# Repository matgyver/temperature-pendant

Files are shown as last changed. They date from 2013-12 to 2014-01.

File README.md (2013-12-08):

/*
 * BlinkM Necklace with temperature sensor and switch
 * This will read in a temperature sensor and set the color
 * of the RGB LED accordingly.  A switch is used to rotate between
 * Temp mode, color mode and simulated off (LED is off, proc still running)
 * 
 * 2013 Matthew E. Nelson - Aerodyne Labs
 * www.rfgeeks.com          www.aerodynelabs.com
 */

/* Notes on this project - Please Read This if you are having problems!

Known Issues

*  There is some delay with the switch and switching modes, this is due to the software PWM, see note below

---------------------------------------------------------------------------------------------------------------

This project uses a BlinkM or MiniM module to read a temp sensor (analog) and use that to control the RGB LED on the module
The BlinkM/MiniM modules have an ATTiny85 (MiniM) or ATTiny44 (BlinkM).  While these processors do have PWM, the pins on the RGB
are not tied to the hardware PWM outputs except for Blue.  Therefore, a software based PWM was needed.  The software PWM that I am
using (see note below on original Author) does a pretty good job, but does have some limitiations.  This is mainly due to the fact 
that the ATTiny processors only have 1 timer.  The values that I choose was picked to produce as smooth of a result I could get while 
keeping the functionaility consistent.

Programming this requires a programmer as the BlinkM or MiniM do not have an arduino comptabible bootloader (or a HW serial port for that matter).  
For this reason you will need an ISP.  Fortunatly you can use an Arduino as an ISP.  Instructions for programming the BlinkM and MiniM can be 
found on ThingM's blog:  http://blog.thingm.com/2011/03/blinkm-smart-led-as-the-smallest-arduino/.  It's a little dated but still applies.

In addition, you will need to add the ATTiny44 and 85 processors to the Arduino IDE.  You can information about this on MIT's website located
here:  http://hlt.media.mit.edu/?p=1695.  There is a known issue with the Arduino IDE being able to address the full 8KB on the processor.  To fix
this issue, see this:  https://github.com/TCWORLD/ATTinyCore/tree/master/PCREL%20Patch%20for%20GCC.  Basically there is a problem with the version
of the compilier that Arduino uses, so this patch will fix that bug that limits it from compiling for programs larger than 4KB.  

UPDATE!
Through this process I ended up switching cores.  This was mainly due to the addition of using an ISR.  You can find the core I used here https://code.google.com/p/arduino-tiny/

Another note on the ISR.  The ISR does indeed work, however since the softwarePWM also uses that timer, it has to finish that before it goes to the ISR.  The result is that if
you push the button and it is pulsing a color, it will not move to the next mode until the the fade is complete.  Remember, it's a "feature".

The Software PWM routine was original written by Ernst Christensen and was found in the following Arduino forum thread: 
http://arduino.cc/forum/index.php/topic,75334.0.html

All credit goes to him for the handy routine

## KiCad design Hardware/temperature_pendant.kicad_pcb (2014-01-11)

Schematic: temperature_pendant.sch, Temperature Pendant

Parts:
BT1: BATTERY
C1, C3: .1 uF
C2: 4.7uF
D1: LED
J1: CONN-6
J2: USB_MINI
R1: 330
R2: 2K
R3: 10k
SW1: SW-MOM
U1: MCP73831/2
U2: BLINKM/MINM
U3: TMP3X

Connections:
+BATT: BT1.1 (+), C1.1, C3.2, J1.3, SW1.2, U1.3 (V_BAT), U2.3 (Vdd), U3.1 (Vs)
GND: BT1.2 (-), C1.2, C2.2, C3.1, J1.2, J2.5, R2.2, R3.2, U1.2 (Vss), U2.2 (GND), U3.3 (GND)
MISO: J1.6, U2.6 (MISO)
unnamed: R2.1, U1.5 (PROG)
unnamed: D1.1 (A), R1.1
unnamed: D1.2 (K), U1.1 (STAT)
unnamed: C2.1, J2.1, R1.2, U1.4 (V_DD)
RST: J1.1, U2.1 (RST)
SW: J1.4, R3.1, SW1.1, U2.4 (SDA/PWM)
TEMP: J1.5, U2.5 (SCL/AIN), U3.2 (Vout)

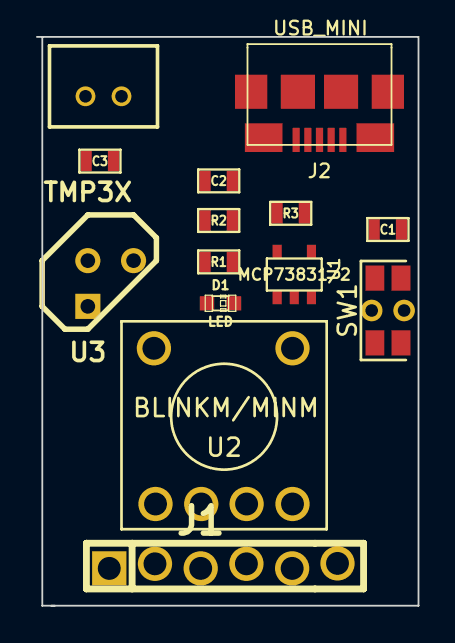
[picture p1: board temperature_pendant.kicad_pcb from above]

Board: 2 copper layers, 21.2 x 31.6 mm, 14 parts (0 on the bottom side), 10 nets, no tracks yet.

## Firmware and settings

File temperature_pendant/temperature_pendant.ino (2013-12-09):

/*
 * BlinkM Necklace with temperature sensor and switch
 * This will read in a temperature sensor and set the color
 * of the RGB LED accordingly.  A switch is used to rotate between
 * Temp mode, color mode and simulated off (LED is off, proc still running)
 * 
 * 2013 Matthew E. Nelson - Aerodyne Labs
 * www.rfgeeks.com          www.aerodynelabs.com
 */

/* Notes on this project - Please Read This if you are having problems!

Known Issues

*  There is some delay with the switch and switching modes, this is due to the software PWM, see note below

---------------------------------------------------------------------------------------------------------------

This project uses a BlinkM or MiniM module to read a temp sensor (analog) and use that to control the RGB LED on the module
The BlinkM/MiniM modules have an ATTiny85 (MiniM) or ATTiny44 (BlinkM).  While these processors do have PWM, the pins on the RGB
are not tied to the hardware PWM outputs except for Blue.  Therefore, a software based PWM was needed.  The software PWM that I am
using (see note below on original Author) does a pretty good job, but does have some limitiations.  This is mainly due to the fact 
that the ATTiny processors only have 1 timer.  The values that I choose was picked to produce as smooth of a result I could get while 
keeping the functionaility consistent.

Programming this requires a programmer as the BlinkM or MiniM do not have an arduino comptabible bootloader (or a HW serial port for that matter).  
For this reason you will need an ISP.  Fortunatly you can use an Arduino as an ISP.  Instructions for programming the BlinkM and MiniM can be 
found on ThingM's blog:  http://blog.thingm.com/2011/03/blinkm-smart-led-as-the-smallest-arduino/.  It's a little dated but still applies.

In addition, you will need to add the ATTiny44 and 85 processors to the Arduino IDE.  You can information about this on MIT's website located
here:  http://hlt.media.mit.edu/?p=1695.  There is a known issue with the Arduino IDE being able to address the full 8KB on the processor.  To fix
this issue, see this:  https://github.com/TCWORLD/ATTinyCore/tree/master/PCREL%20Patch%20for%20GCC.  Basically there is a problem with the version
of the compilier that Arduino uses, so this patch will fix that bug that limits it from compiling for programs larger than 4KB.  

UPDATE!
Through this process I ended up switching cores.  This was mainly due to the addition of using an ISR.  You can find the core I used here https://code.google.com/p/arduino-tiny/

Another note on the ISR.  The ISR does indeed work, however since the softwarePWM also uses that timer, it has to finish that before it goes to the ISR.  The result is that if
you push the button and it is pulsing a color, it will not move to the next mode until the the fade is complete.  Remember, it's a "feature".

The Software PWM routine was original written by Ernst Christensen and was found in the following Arduino forum thread: 
http://arduino.cc/forum/index.php/topic,75334.0.html

All credit goes to him for the handy routine
*/

#include "PinChangeInterrupt.h"
// BlinkM / MinM pins
const int redPin = 3;  // 
const int grnPin = 4;  //
const int bluPin = 1;  // PWM, will blink when programming
const int sdaPin = 0;  // PWM, 'd' pin, can be digital I/O
const int sclPin = 2;  // A/D, 'c' pin, can be digital I/O, or analog input

volatile long lastDebounceTime = 0;   // the last time the interrupt was triggered

//Defines
#define fadeSpeed 15             //Defines how fast we fade in the SoftPWM routine

//the debounce time in ms; decrease if quick button presses are ignored, increase
//if you get noise (multipule button clicks detected by the code when you only pressed it once)
#define debounceDelay 50         

//Defines the 2.56V internal voltage reference for use in the analogReference function
#define INTERNAL2V56_NO_CAP (6)

//Variable setup and initialize
int SW_Pin = sdaPin;             //Digital in pin for reading switch
const int tmp36_Pin  = A1;       //Analog in pin for TMP36 temp sensor and A1 because Arduino is stupid
const int numReadings = 10;      //Number of readings to take to average out the values

//Setup variables and set default values
int temperature = 0;
int mode = 1;

//Array used for averaging temperature values
int readings[numReadings];
int index = 0;
int total = 0;
int average = 0;
//Set RGB values to zero
int r,g,b = 0;

//  Setup routine, configures our pins and initializes a few things
void setup() 
{
  
  // initialize all the readings and array to 0 
  for (int thisReading = 0; thisReading < numReadings; thisReading++)
    readings[thisReading] = 0;   
  //configures the pins to the BlinkM module
  pinMode(redPin, OUTPUT);
  pinMode(grnPin, OUTPUT);
  pinMode(bluPin, OUTPUT); 

// Configures the Switch and TMP36 sensor pins
  pinMode(SW_Pin, INPUT);
  digitalWrite(SW_Pin, LOW);
  pinMode(tmp36_Pin, INPUT);
  
//Turn on the internal voltage reference for ADC since our source voltage varies, uses the ATTiny 2.56V internal ref.
  analogReference(INTERNAL2V56_NO_CAP);  
  
//Setup interrupt for switching modes
  attachPcInterrupt(0,SWITCH_ISR,RISING);
  
//  This is a short "Hello" to show we have initialized and setup everything
// This will blink each color once to make sure the RGB LED is functioning

  digitalWrite(grnPin, HIGH);     
  delay(250);
  digitalWrite(grnPin, LOW);
  delay(250);
  digitalWrite(bluPin, HIGH);     
  delay(250);
  digitalWrite(bluPin, LOW);
  delay(250);
  digitalWrite(redPin, HIGH);     
  delay(250);
  digitalWrite(redPin, LOW);
  delay(250);
  digitalWrite(redPin, HIGH);
  digitalWrite(bluPin, HIGH);
  digitalWrite(grnPin, HIGH);
  delay(250);
  digitalWrite(redPin, LOW);
  digitalWrite(bluPin, LOW);
  digitalWrite(grnPin, LOW);
  delay(250);
}

//  Main Loop

void loop() 
{
  if (mode > 6) 
    mode = 1;
    
    switch (mode) {
      case 1:  //Set LED color based on temp, default mode
        set_color_by_temp();
        break;
      case 2: //Rotate flashing each pin on the RGB
        flash_rgb();
        break;
      case 3: //Pulse a purple color
        pulse_purple();
        break;
      case 4: //Pulse a red color
        pulse_red();
        break;
      case 5: //Pulse a white color
        pulse_white();
        break;
      case 6: //"Off" mode, not a true off, but we are not burning current in the LEDs
        digitalWrite(redPin, LOW);
        digitalWrite(bluPin, LOW);
        digitalWrite(grnPin, LOW);
        delay(250);
        break;
      default:
        mode = 1;     
  
  }

}

/* Switch ISR Routine
This routine handles the switch and debounce.  If the switch is pressed, we want to increment the mode
We also want to handle a debounce on the switch, so we use the millis function to count so much before
actually acting on the switch, if the switch is still pressed, we increment
Because of the millis function, this ISR can not happen right away when the LEDs are using the Software PWM
So there will be a delay during these times until the fade is complete.  Consider this a "feature"
*/
void SWITCH_ISR(){
  
  if ((millis() - lastDebounceTime) > debounceDelay) //if current time minus the last trigger time is greater than
    {                                                  //the delay (debounce) time, button is completley closed.
      lastDebounceTime = millis();
   
      mode++;
    }

}

//This function reads the temp sensor and then sets the color of the RGB based on that value
void set_color_by_temp (void) {

  int sensorValue = analogRead(tmp36_Pin);
  int temperature = sensorValue * 2.56; 
  
/* Average routine
   In order to help smooth out the readings, we will take several measurements
   and average them out.  This does mean that upon initial startup, it will start
   at zero and pulse blue.  Once enough readings have been taken it will go to the 
   right color
   */
   
  // subtract the last reading:
  total = total - readings[index]; 
  
  // read from the sensor:  
  readings[index] = temperature; 
  
  // add the reading to the total:
  total = total + readings[index];       
  
  // advance to the next position in the array:  
  index = index + 1;                    

  // if we're at the end of the array...
  if (index >= numReadings)              
    // ...wrap around to the beginning: 
    index = 0;                           

  // calculate the average:
  temperature = total / numReadings;
  
  //Here we determine the color base on the readings in millivolts.  This was done as doing
  //a full conversion to a temperature was causing some issues.  We are not sending out the temp data
  //so there is no need for this, but using the millivolts value does keep it fairly easy to read
  
  //If less than 0 C, pulse blue
  if (temperature < 500)
  {
    for(int fadeValue = 1; fadeValue < 254; fadeValue++) { 
    softPWM(bluPin, fadeValue, fadeSpeed);
    digitalWrite(grnPin, LOW);
    digitalWrite(redPin, LOW);
    }
    
    for(int fadeValue = 253; fadeValue > 1; fadeValue--) { 
    softPWM(bluPin, fadeValue, fadeSpeed);
    digitalWrite(grnPin, LOW);
    digitalWrite(redPin, LOW);
    }
  }
  //If between 0 and 25 C, fade from blue to green
  else if(temperature < 750 && temperature >= 500)
  {
    g = map(temperature, 500, 750, 1, 254);
    b = map(temperature, 500, 750, 254, 1);
    softPWM(grnPin, g, fadeSpeed);
    softPWM(bluPin, b, fadeSpeed);
    digitalWrite(redPin, LOW);
    
  }
  //If between 25 and 50 C, fade from green to red
  else if(temperature < 950 && temperature >= 750)
  {
    r = map(temperature, 750, 950, 1, 254);
    g = map(temperature, 750, 950, 254, 1);
    softPWM(grnPin, g, fadeSpeed);
    softPWM(redPin, r, fadeSpeed);
    digitalWrite(bluPin, LOW);
    
  }
  
  //If the temperature is hot, over 50 C, pulse red quickly
  else if (temperature >= 950)
  {
    for(int fadeValue = 1; fadeValue < 254; fadeValue++) { 
    softPWM(redPin, fadeValue, 5);
    digitalWrite(grnPin, LOW);
    digitalWrite(bluPin, LOW);
    }
    
    for(int fadeValue = 253; fadeValue > 1; fadeValue--) { 
    softPWM(redPin, fadeValue, 5);
    digitalWrite(grnPin, LOW);
    digitalWrite(bluPin, LOW);
    }
  }
}

//This routine flashes each RGB LED in sequence and the speed depends on the temperature value
void flash_rgb(void) {
  
  //Read the sensor, convert to milliVolt
  int sensorValue = analogRead(tmp36_Pin);
  int temperature = sensorValue * 2.56; 
  
  //Map the millis to a range of delay values
  int sp = map(temperature, 500, 950, 350, 100);
  
  digitalWrite(grnPin, HIGH);     
  delay(sp);
  digitalWrite(grnPin, LOW);
  delay(sp);
  digitalWrite(bluPin, HIGH);     
  delay(sp);
  digitalWrite(bluPin, LOW);
  delay(sp);
  digitalWrite(redPin, HIGH);     
  delay(sp);
  digitalWrite(redPin, LOW);
  delay(sp);
  digitalWrite(redPin, LOW);
  digitalWrite(bluPin, LOW);
  digitalWrite(grnPin, LOW);
  delay(sp);
}

void pulse_purple(void) {
  int fadeValue = 0;
  
  // fade in from min to max in increments of 5 points:
  for(int fadeValue = 1; fadeValue < 254; fadeValue++) { 
    // sets the value (range from 0 to 255):
    digitalWrite(grnPin, LOW);
    softPWM(redPin, fadeValue, fadeSpeed);
    softPWM(bluPin, fadeValue, fadeSpeed);
                         
  } 

  // fade out from max to min in increments of 5 points:
  for(int fadeValue = 254; fadeValue > 1; fadeValue--) { 
    // sets the value (range from 0 to 255):
    digitalWrite(grnPin, LOW);
    softPWM(redPin, fadeValue, fadeSpeed);
    softPWM(bluPin, fadeValue, fadeSpeed);                        
  }
}

void pulse_white(void) {
  int fadeValue = 0;
  
  // fade in from min to max in increments of 5 points:
  for(int fadeValue = 1; fadeValue < 254; fadeValue++) { 
    // sets the value (range from 0 to 255):
    softPWM(grnPin, fadeValue, fadeSpeed);
    softPWM(redPin, fadeValue, fadeSpeed);
    softPWM(bluPin, fadeValue, fadeSpeed);
                         
  } 

  // fade out from max to min in increments of 5 points:
  for(int fadeValue = 254; fadeValue > 1; fadeValue--) { 
    // sets the value (range from 0 to 255):
    softPWM(grnPin, fadeValue, fadeSpeed);
    softPWM(redPin, fadeValue, fadeSpeed);
    softPWM(bluPin, fadeValue, fadeSpeed);                        
  }
}

void pulse_red(void) {
  int fadeValue = 0;
  
  // fade in from min to max in increments of 5 points:
  for(int fadeValue = 1; fadeValue < 254; fadeValue++) { 
    // sets the value (range from 0 to 255):
    digitalWrite(grnPin, LOW);
    softPWM(redPin, fadeValue, fadeSpeed);
    digitalWrite(bluPin, LOW);
                         
  } 

  // fade out from max to min in increments of 5 points:
  for(int fadeValue = 254; fadeValue > 1; fadeValue--) { 
    // sets the value (range from 0 to 255):
    digitalWrite(grnPin, LOW);
    softPWM(redPin, fadeValue, fadeSpeed);
    digitalWrite(bluPin, LOW);                        
  }
}

//software PWM function that fakes analog output
// Function reads in the pin,  duty cycle (brightness), and fade speed)
// Duty cycle is 1-254
void softPWM(int pin, int freq, int sp) {
  digitalWrite(pin,HIGH); //on
  delayMicroseconds(sp*freq);
  digitalWrite(pin,LOW); //off
  delayMicroseconds(sp*(255-freq));
}

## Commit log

2013-10-21 Initial commit on hardware
    Start on schematic
    [temperature_pendant.sch]
2013-10-22 Added additional components
    Added BlinkM andprogramming header to schematic.
    [temperature_pendant.sch]
2013-10-26 Updates
    Completed schematic. Minor revisions, added comments to Arduino code.
    Fixed Library reference issue.
    [temperature_pendant.sch]
2013-10-26 PCB added
    First cut of the PCB layout
    [temperature_pendant.kicad_pcb]
2013-10-27 Updated board
    Updated board and first revision routing
    [temperature_pendant.dsn, temperature_pendant.kicad_pcb, temperature_pendant.sch]
2013-10-28 Added Gerber files
    Added Gerber and 3D file
    [temperature_pendant-B_Cu.gbl, temperature_pendant-B_Mask.gbs, temperature_pendant-B_SilkS.gbo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]
2013-11-05 Fixed Gerber issue
    Fixed Gerber issue
    [temperature_pendant.kicad_pcb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]
2013-11-06 Added drill hole
    Added a mechanical hole that could be used for chain for the pendant.
    [temperature_pendant.kicad_pcb]
2013-11-17 Updates
    Minor updates based on testing with the actual board.
2013-11-17 Fixed sensor, added locking connector
    Fixed the backward wiring on the sensor, added locking connector. Fixes
    issue #4 for the sensor and issue #3 for the locking connector.
    [temperature_pendant.kicad_pcb]
2013-11-17 Minor change cleanup
    Moved switch and battery connector. Cleaned up tracks in preparation
    for a redo on the layout.
    [temperature_pendant.kicad_pcb]
2013-11-17 Final cleanup and new routed board
    Re-routed board based on new placement
    [temperature_pendant.dsn, temperature_pendant.kicad_pcb]
2013-12-02 Added ISR routine
    Added a ISR to better handle the button presses to switch modes.
    Cleaned up other aspects of the code. Still have some debugging to
    do...
2013-12-03 Added debounce
    Added debounce routine to ISR to better handle switch. HW change will
    also help address some issues in the next HW Rev. Cleaned up some code,
    tweaked temperature mapping values. Added some other "flashy" modes.
    [temperature_pendant.ino]
2013-12-07 Enabled built-in pull ups
    Enabled built-in pull down resistor to better stabilize the SW input.
    Testing if I still need an external pull-down but for now added one in
    the schematic.
    [temperature_pendant.sch]
2013-12-08 Fixed issues
    Fixed several issues. In the schematic added pull-down resistor and
    also some caps to improve performance and noise issues. Re-wrote the
    temperature reading routine and color picking. Enabled the internal
    voltage reference and set to 2.56 VDC reference voltage. This means the
    values won't change as the battery voltage drops over time. Cleaned up
    various parts of the code. Tested to work so far on the rev1 boards.
    [temperature_pendant.sch]
2013-12-08 Update README.md
    Added information about switching ATTiny Core and ISR
2013-12-09 Clean up, change to function
    Cleaned up the code some more, removed extra variables, comments and
    re-organized. Changed the RGB rotation to change the speed of the
    rotation based on the temperature, the hotter it is, the faster it will
    go.
2013-12-09 Updated PCB
    Updated PCB with changes done to schematic. made the board longer but
    not as wide.
    [$temperature_pendant.sch, temperature_pendant.kicad_pcb]
2013-12-09 Minor update
    [$temperature_pendant.sch, temperature_pendant.sch]
2014-01-11 Added MCP73831 Charger
    Deceided to design around using a 3.7 Li-Poly flat pack battery. To
    make it more user friendly (ie don't need to fumble getting the battery
    out) I have added a MCP73831 Charger. Currently set to 500 mA charge.
    This should be fine for any Li-Poly battery that has a maximum voltage
    of 4.2 and a minimum capacity of 500 mAh. Batteries with smaller
    capacity may be damaged by the higher charge current as most batteries
    are a 1C charge rate.
    [temperature_pendant.sch]
2014-01-11 updated PCB
    Updated PCB layout with new charger and a few other changes to packages.
    Swapped out JST connector for the smaller PH series.
    [temperature_pendant.kicad_pcb]
2014-01-11 Switched to MinM
    Switched to MinM board in Master branch
    [temperature_pendant.kicad_pcb]
